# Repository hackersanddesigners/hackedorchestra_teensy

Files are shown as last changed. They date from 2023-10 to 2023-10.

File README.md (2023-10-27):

 

# HACKED ORCHESTRA - TEENSY WORKSHOP

Documentation for Sound Parasites developed for the Hacked Orchestra workshops (H&D, Ghenwa Noiré, Sonic Acts, Muziekgebouw aan het IJ, funded by AFK and Stifo). We've built two types of sound parasites to be used with active components on the line in (e.g. bicycle dynamos, solar panels, piezo transducers, pick up coils) that pick up sounds around us hidden in textures and different materials. One sound parasite adds an echo/delay and the other one adds a granular effect and pitchshifting. Both have a reverb switch implemented as well. 

The sound parasites can be mounted in tin cans (saluting the early DIY electronic instrument builders), but for the purposes of this workshop we will stick to breadboarding because it is easier to troubleshoot in a workshop setting.

This work is inspired by Nic Collins' *Handmade Electronic Music* and Paul Stoffsregen's work on the Teensy + Audio Module as shown in [this workshop](https://www.pjrc.com/store/audio_tutorial_kit.html). 

## Workshop outline 13 oct 23

Check it out here: 

[https://etherpad.hackersanddesigners.nl/p/HackedOrchestra_13Oct](https://etherpad.hackersanddesigners.nl/p/HackedOrchestra_13Oct)

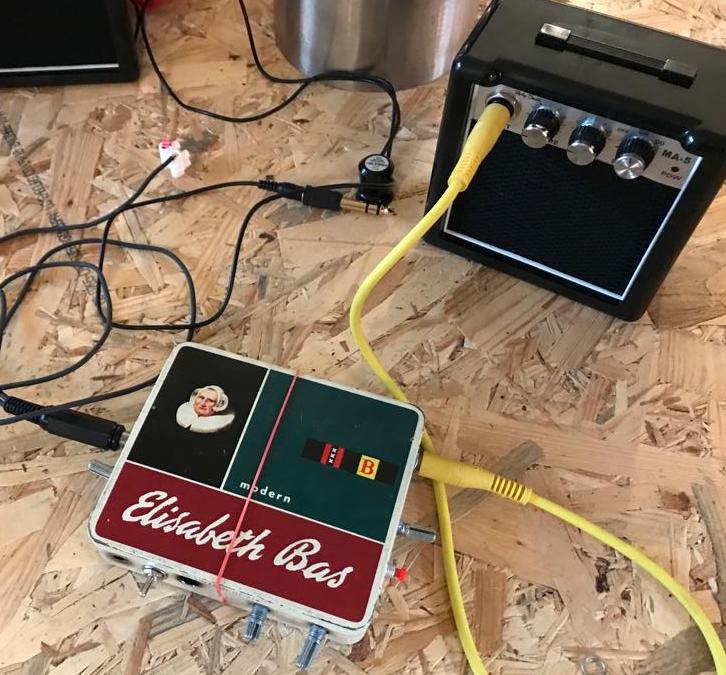
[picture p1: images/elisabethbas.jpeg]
 

### Wishlist based on workshop

* ~~rising/fallingEdge function not great fit w toggle switch, change to simple digitalRead~~
* find out how to protect line in
* ~~more descriptive serial output for the effect sketches (DONE)~~
* ~~controlling line in level w knob doesnt seem to work? (FIXED)~~
* ~~re-do wiring diagram (DONE)~~
* ~~write equalizer code for low pass, high pass, band pass filter (DONE)~~

## BOM 

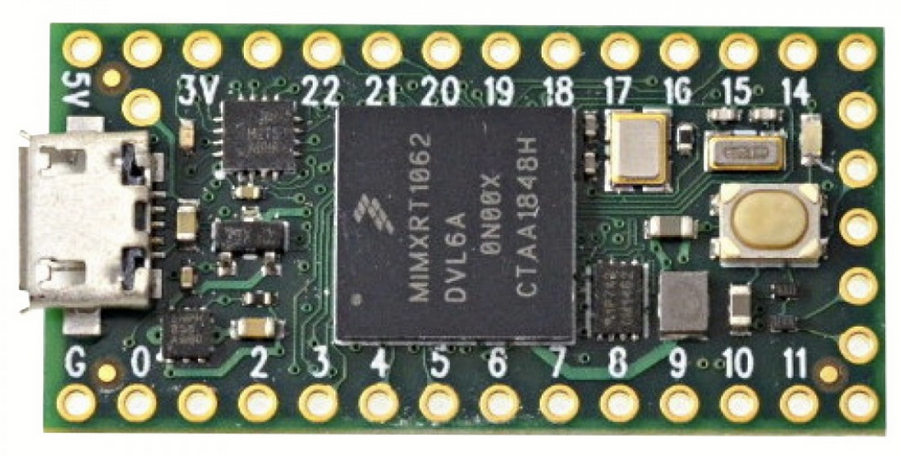
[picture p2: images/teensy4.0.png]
 
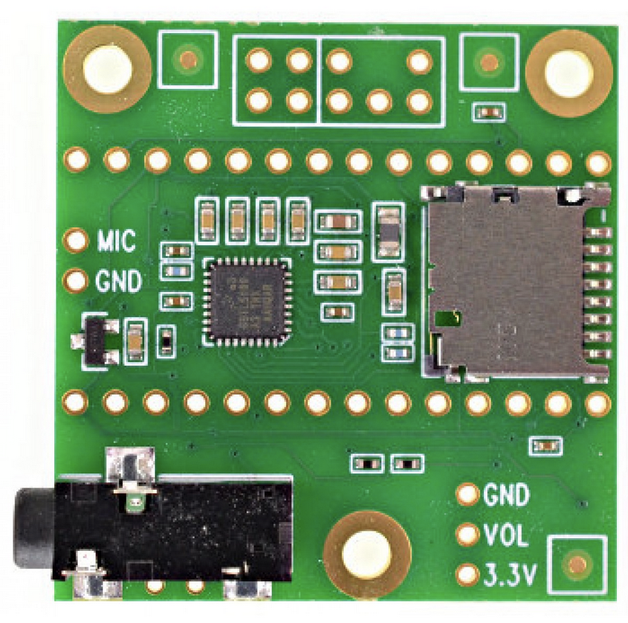
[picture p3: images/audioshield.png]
 

* [Teensy 4.0 - without headers](https://www.tinytronics.nl/shop/en/development-boards/microcontroller-boards/teensy/teensy-4.0) € 27,50 via TinyTronics or Open Circuit
* [Teensy Audio Adapter Board for Teensy 4.0](https://www.tinytronics.nl/shop/en/development-boards/accessories/adapter-boards/teensy-audio-adapter-board-for-teensy-4.0) € 16,25 via TinyTronics or Open Circuit
* [Male pin header, 2x 14 positions](https://www.tinytronics.nl/shop/en/cables-and-connectors/connectors/pin-headers/male/40-pins-header-male) € 0,50 via TinyTronics
* [Breakaway male header 90 degrees](https://www.tinytronics.nl/shop/en/cables-and-connectors/connectors/pin-headers/male/40-pins-header-male-90-degrees) € 0,50 via TinyTronics 
* [Female header 11 mm pin height, scored and broken into 2 rows of 14 positions](https://www.tinytronics.nl/shop/en/cables-and-connectors/connectors/pin-headers/female/40-pins-header-female-11mm-pin-height) € 1 via TinyTronics
* [Micro USB cable](https://www.tinytronics.nl/shop/en/cables-and-connectors/cables-and-adapters/usb/micro-usb/micro-usb-cable-50cm) € 1,24 via TinyTronics
* 4x [10k potentiometer, breadboard compatible](https://www.tinytronics.nl/shop/en/components/resistors/potentiometers/10k%CF%89-potmeter-standard) € 0,41 each via TinyTronics
* Dupont jumper wires, male-male and male-female
* 2x[Jack chassis 6.3 mm](https://www.allekabels.nl/jack-stekker/42/1307777/jack-chassisdeel.html) € 0,99 alle kabels
* [6,3 mm jack patch cables, set](https://www.conrad.nl/nl/p/paccs-jack-kabel-6x-jackplug-male-6-3-mm-6x-jackplug-male-6-3-mm-30-00-cm-meerkleurig-301277.html) € 6.99 Conrad 
* battery-powered mini guitar amp with 6.3 mm jack line in/out [e.g.](https://www.thomannmusic.com/harley_benton_ma_5_miniamp.htm) € 15
* [Piezo transducers](https://www.tinytronics.nl/shop/en/audio/speakers/buzzers/piezo-electronic-buzzer-with-soldered-wires-35mm) € 0,41 Tinytronics
* Bicycle dynamos, second-hand/salvaged
* 2x[Solar cells 5V ](https://www.tinytronics.nl/shop/en/power/solar-energy/solar-panels/solar-panel-5v-200ma-110x80mm) € 2,89
* [Telephone pick-up mic](https://www.amazon.com/Telephone-Microphone-Suction-Cup-Pickup/dp/B0034I75IK) € 8
* [Terminal strip](https://www.tinytronics.nl/shop/en/cables-and-connectors/connectors/screw-terminals/terminal-strip-12-lanes) € 1,24 Tinytronics
* [Shielded audio cable](https://www.conrad.nl/nl/p/bkl-electronic-1509008-audiokabel-1-x-0-22-mm-zwart-per-meter-457893.html) € 1,49 per meter, Conrad
* 4x [Solderable mono jack plugs 6.35 mm € 0,44](https://www.kabelshop.nl/Nedis-6-35-mm-jack-plug-Nedis-Mono-Mannelijk-CAVC23980BK-i15077-t9799.html)

**Plus:for version with breadboard**
* [Large breadboard](https://www.tinytronics.nl/shop/en/tools-and-mounting/prototyping-supplies/breadboards/breadboard-830-points) € 3,31 tinytronics
* A power bank (or plug USB cable into laptop or wall socket adapter)
* [momentary switch 12mm](https://www.tinytronics.nl/shop/en/switches/manual-switches/pcb-switches/tactile-pushbutton-switch-momentary-4pin-12*12*7.3mm) € 0,12 via tinytronics
* [cap for momentary switch 12 mm](https://www.tinytronics.nl/shop/en/components/knobs,-caps-and-covers/button-cap-for-tactile-pushbutton-switch-momentary-12x12x7.3mm-yellow) €0,12 via Tinytronics
* [toggle switch](https://www.tinytronics.nl/shop/en/switches/manual-switches/slide-switches/small-switch-for-pcb-or-breadboard) € 0,17 via tinytronics

**Plus: for version inside a case** 
* 1x [Momentary switch](https://www.tinytronics.nl/shop/en/switches/manual-switches/push-buttons-and-switches/black-button-7mm) € 0,41 each via TinyTronics
* 1x [toggle switch](https://www.tinytronics.nl/shop/en/switches/manual-switches/toggle-switches/standard-built-in-flip-switch-mts-102) € 0,60 via TinyTronics
* [LilyGO TTGO 18650 battery charging board](https://www.tinytronics.nl/shop/en/power/bms-and-chargers/li-ion-and-li-po/with-protection-circuit/lilygo-ttgo-t-bat-with-18650-battery-holder-cn3065) € 4,55 via tinytronics
* [18650 li-ion battery 3500mAh/10A](https://www.tinytronics.nl/shop/en/power/batteries/18650/lg-18650-li-ion-battery-3400mah-10a-inr18650-mj1) € 4,96 via Tinytronics
* [JST-PH compatibel connector, 2 pos](https://www.tinytronics.nl/shop/en/cables-and-connectors/cables-and-adapters/jst-compatible/jst-2.0mm-connector-with-cable-ph2.0-2-pins) € 0,33 via Tinytronics
* [perfboard 2.54 mm spacing with lanes/strips](https://www.tinytronics.nl/shop/en/tools-and-mounting/prototyping-supplies/experiment-pcbs/experiment-pcb-6.5cm*14.5cm-lanes) €1,65 via TinyTronics

# Sounds Around: Material Symmetries

There are lots of signals around us that can be be sonified and/or amplified. What goes up, must come down, what gives will receive. A speaker is a mic is a speaker, a motor is a generator is a motor. Silent signals, textures, movements, vibrations: all can be explored with these simple probes. Wire one up and find out: 

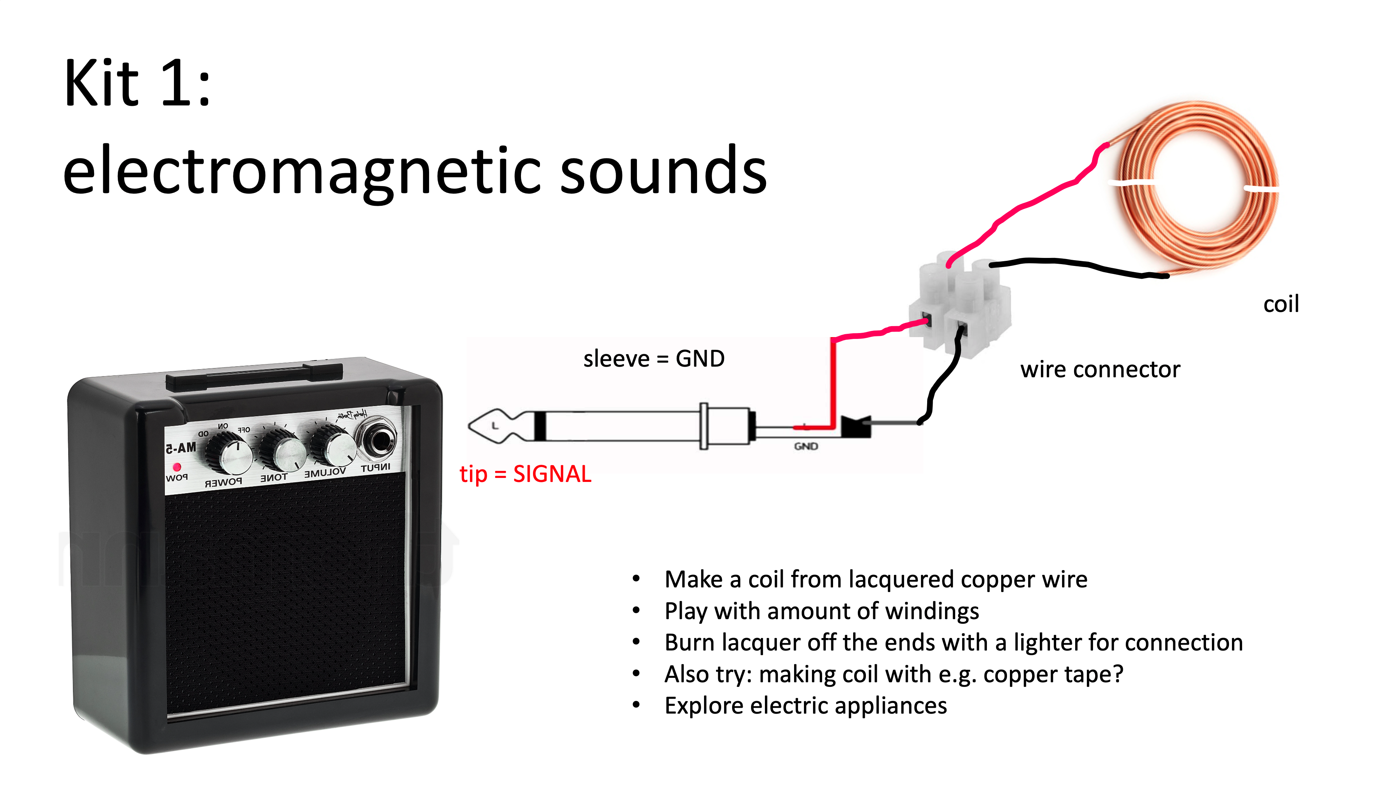
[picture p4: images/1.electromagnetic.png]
 

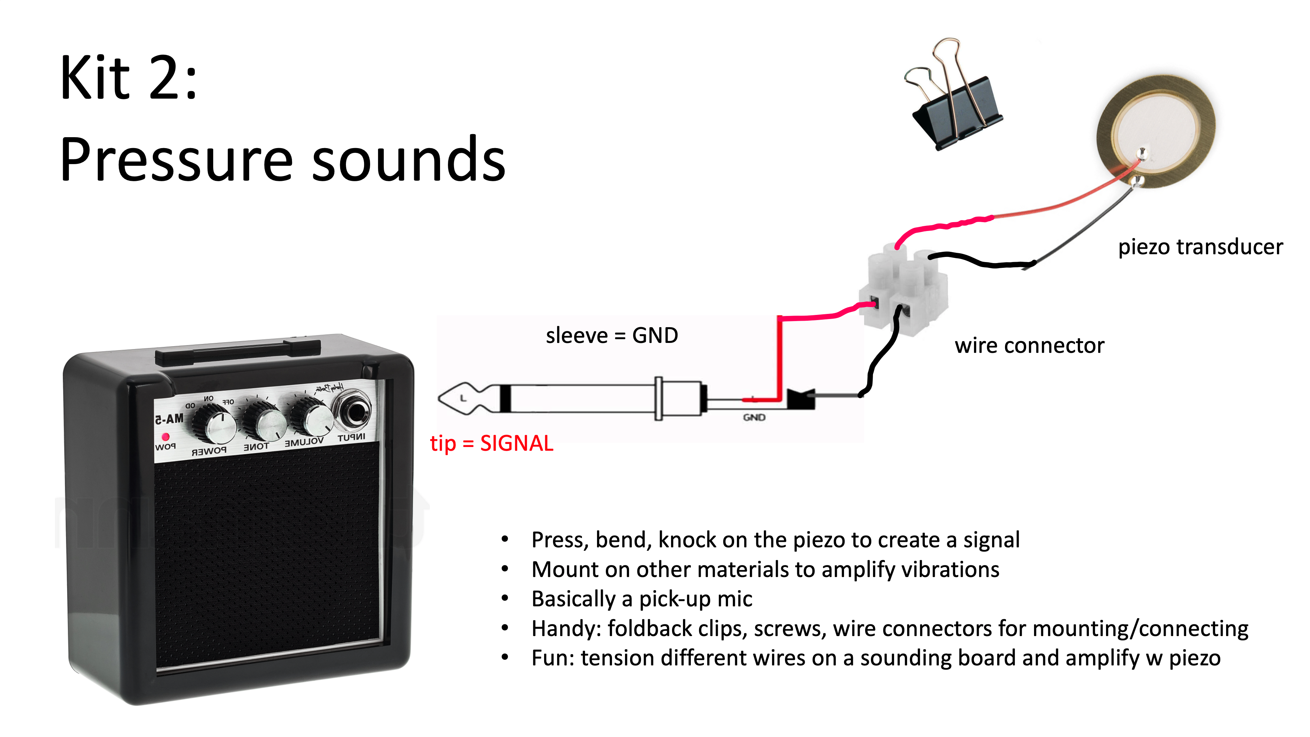
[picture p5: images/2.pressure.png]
 

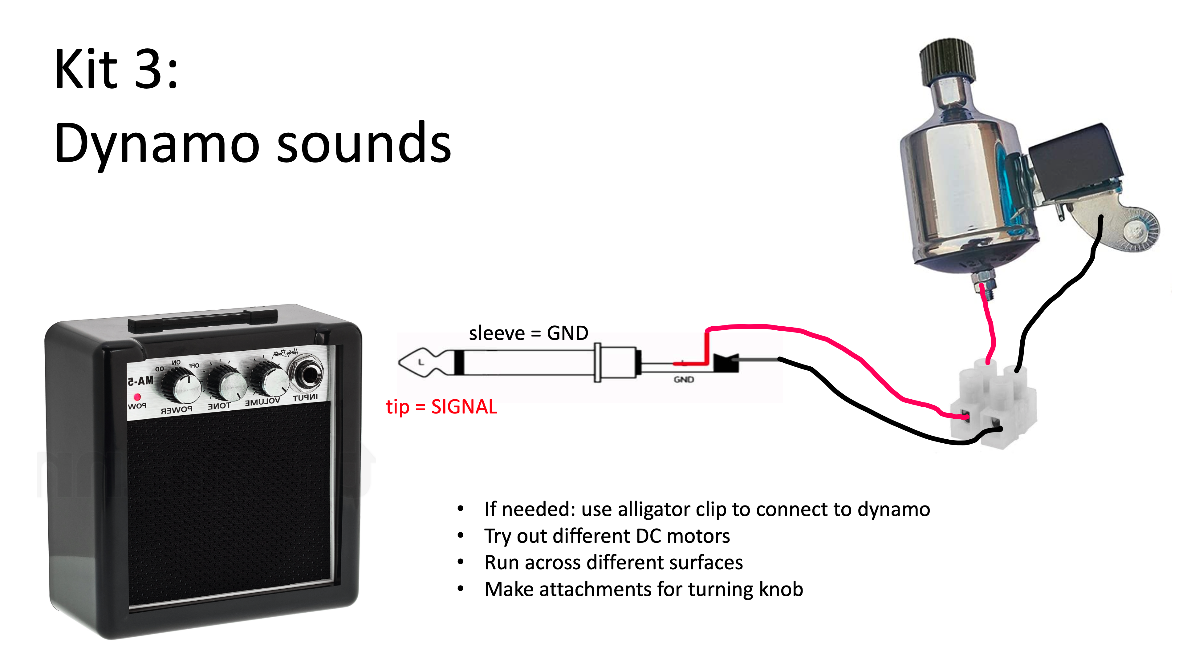
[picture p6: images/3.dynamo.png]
 

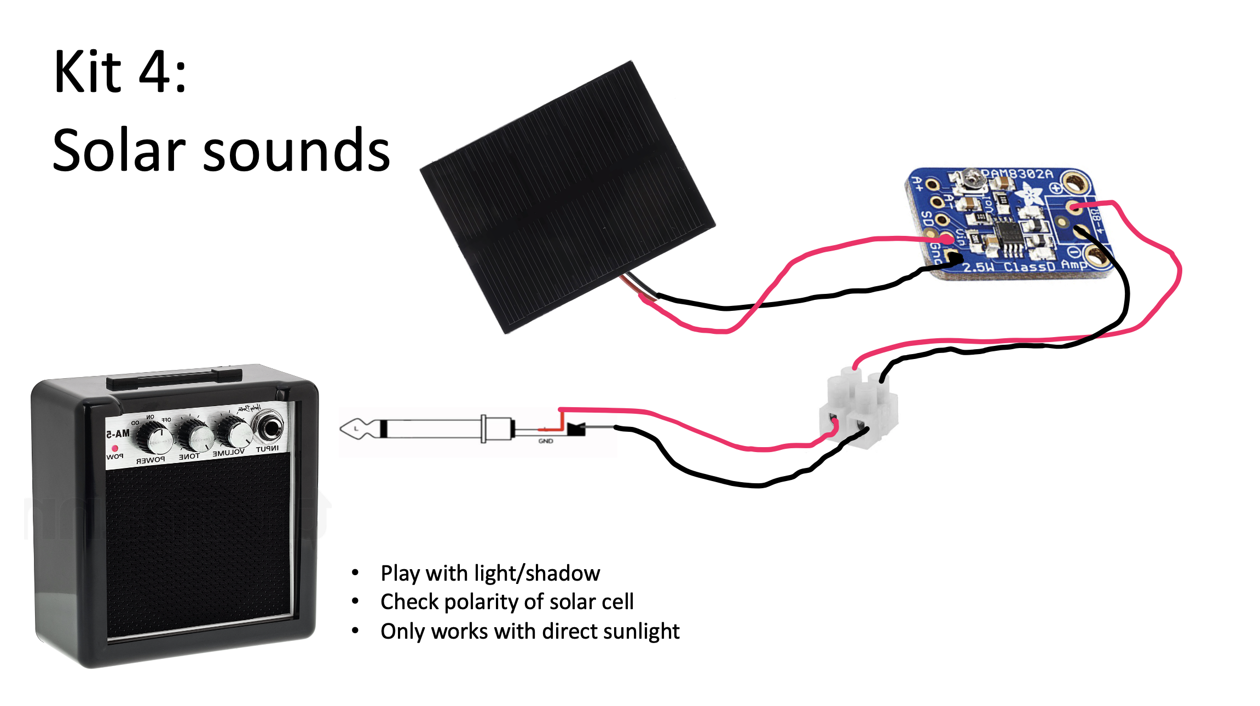
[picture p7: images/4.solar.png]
 

# Building Sound Parasites

## Assembling the circuit

* Score the straight male and female header strips with a stanley knife or dremel and break them into rows of 14. 
* break two pieces from the 90 degree angled header: one with 2 positions and one with 3 positions. 

### Assembling with a breadboard

The teensy board will be pressed into the breadboard, the male pins of the female header should stick out of the bottom of the board. The audio shield will go on top of it, so needs the male header pins sticking out downwards also. So we want to: 

* Solder the female header strips with the long legs through the teensy board 
* solder the male header strips to the bottom of the audio shield
* solder the small angled headers to the line in and line out on the audio shield 

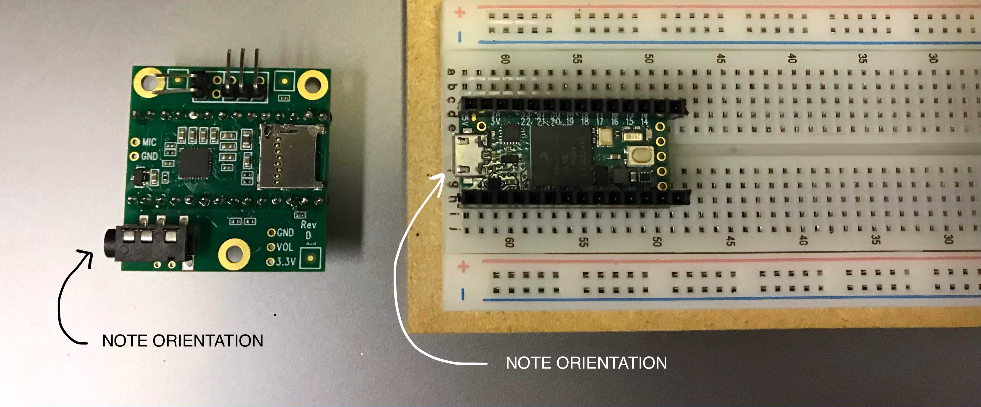
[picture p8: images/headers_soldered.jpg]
 

* Gently press the header on top of the teensy board. Be careful not to bend the legs.

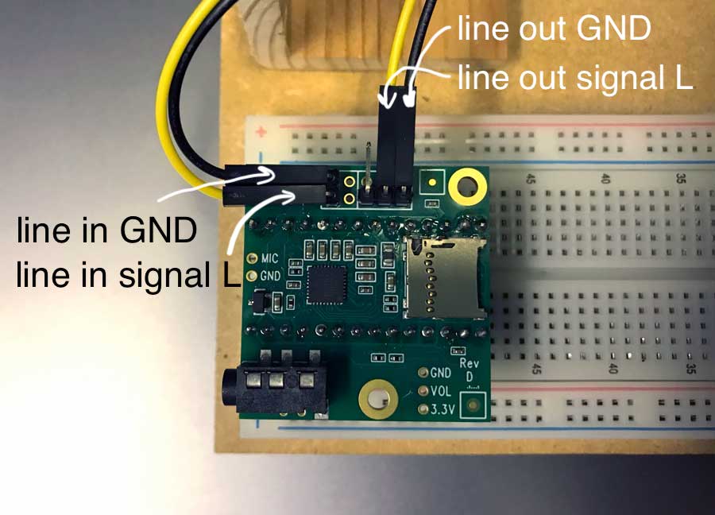
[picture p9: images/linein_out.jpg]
 

* You can connect the left jack receptacle to the LINE IN pins (black to GND, yellow to SIGNAL L)
* And connect the right jack receptacle to the LINE OUT pins (black to GND, yellow to SIGNAL L)

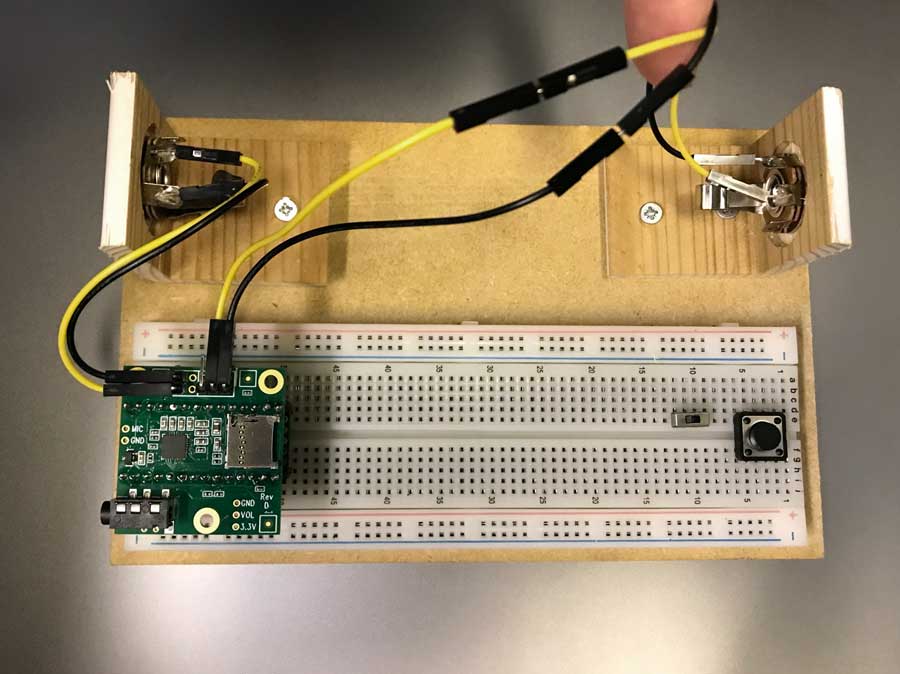
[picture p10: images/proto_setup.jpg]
 

* With this in place you can connect a probe (e.g. a piezo) as input on the line in (left), and a jack cable going to the speaker on the line out (right). 

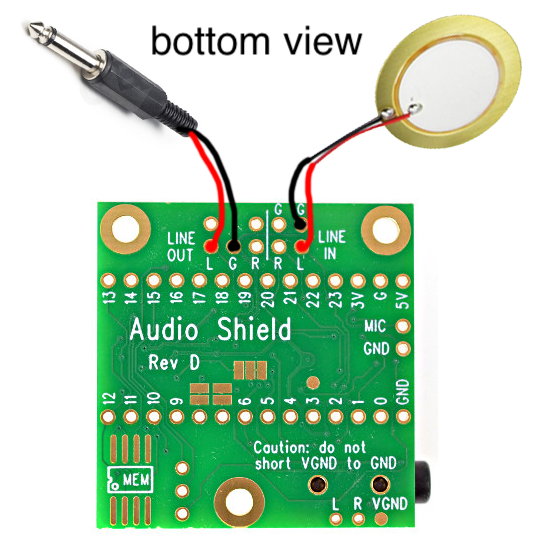
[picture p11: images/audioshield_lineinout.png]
 

**Breadboarding**

You will need to connect 4 potentiometers (turning knobs), a toggle switch, and a momentary switch to the breadboard. You can follow this wiring diagram. You might have a switch that looks slightly different. Just make sure to connect one leg to ground, and the other to the pin 0 (for a slide or toggle switch) or pin 1 for the momentary switch (pushbutton).

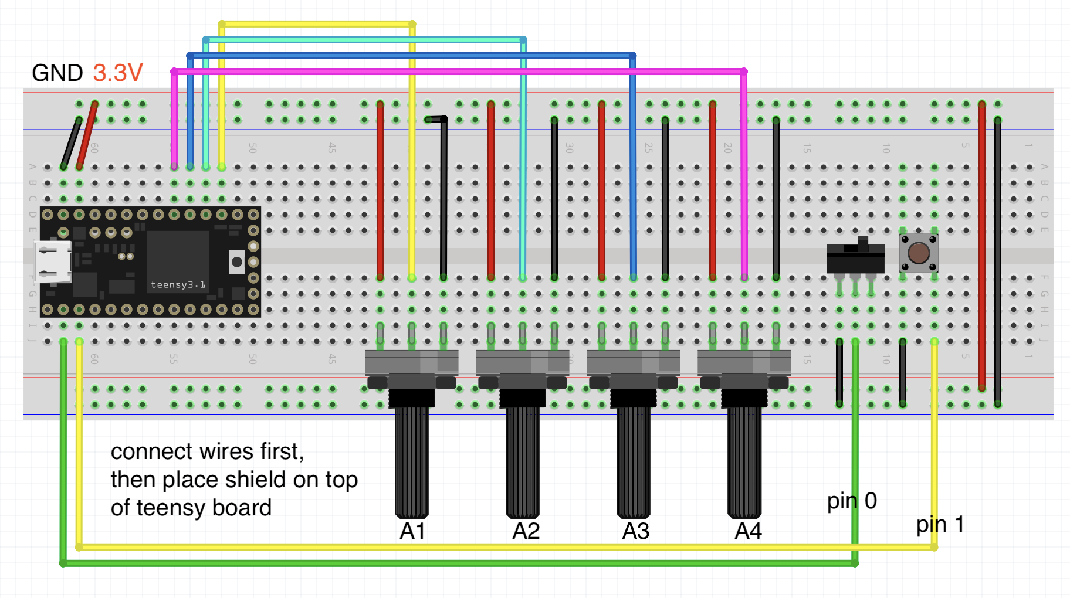
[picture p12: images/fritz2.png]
 

### Assembling inside a box

This requires a slightly different approach because stacking the headers like we did for the breadboard makes the stack really high. So we will bend the stacking headers outwards to keep it more flat.

* bend the female headers with the long leg into a 90 degree angle: stick one into the holes of the board but not all the way (leave 1 mm to allow for bending) and bend them to 90 degree angle.  
* solder them to the teensy board
* solder the straight male header strips to the audio shield
* solder the small angled headers to the line in and line out on the audio shield

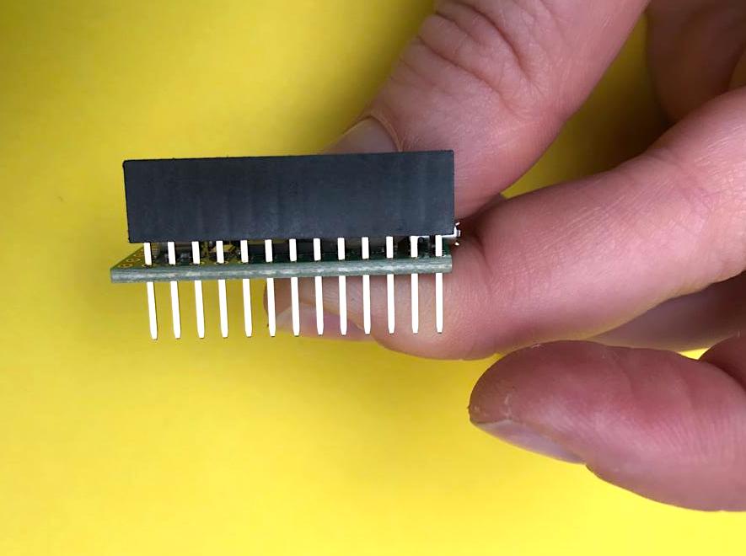
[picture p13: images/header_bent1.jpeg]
 
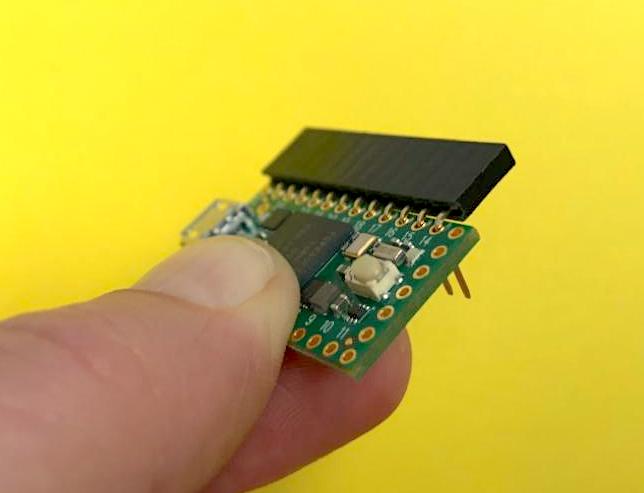
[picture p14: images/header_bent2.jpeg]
 
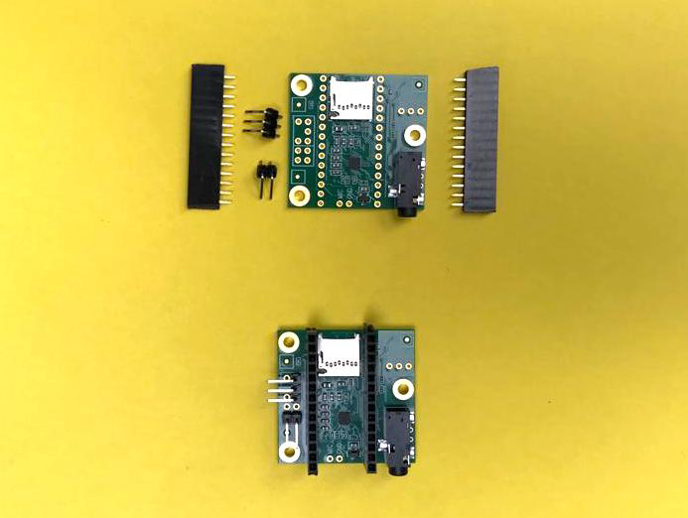
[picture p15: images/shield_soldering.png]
 
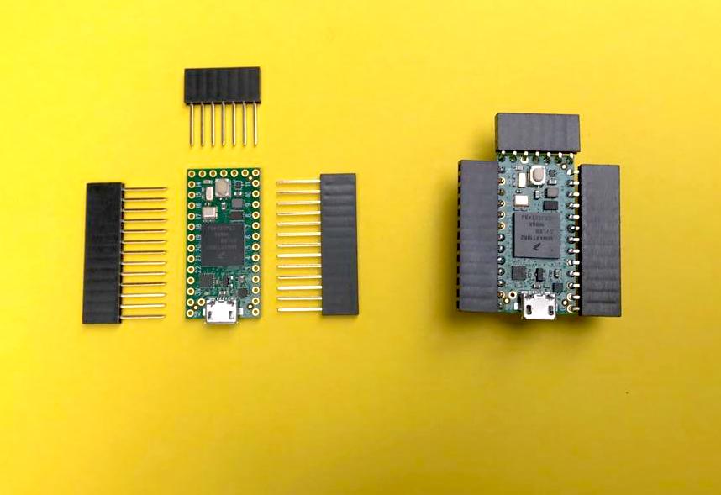
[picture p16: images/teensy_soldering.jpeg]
 

## Install for Mac & Arduino 2.2.x.

Add link below to the JSON board manager URL in the preference panel of Arduino IDE: 

```
https://www.pjrc.com/teensy/package_teensy_index.json
```

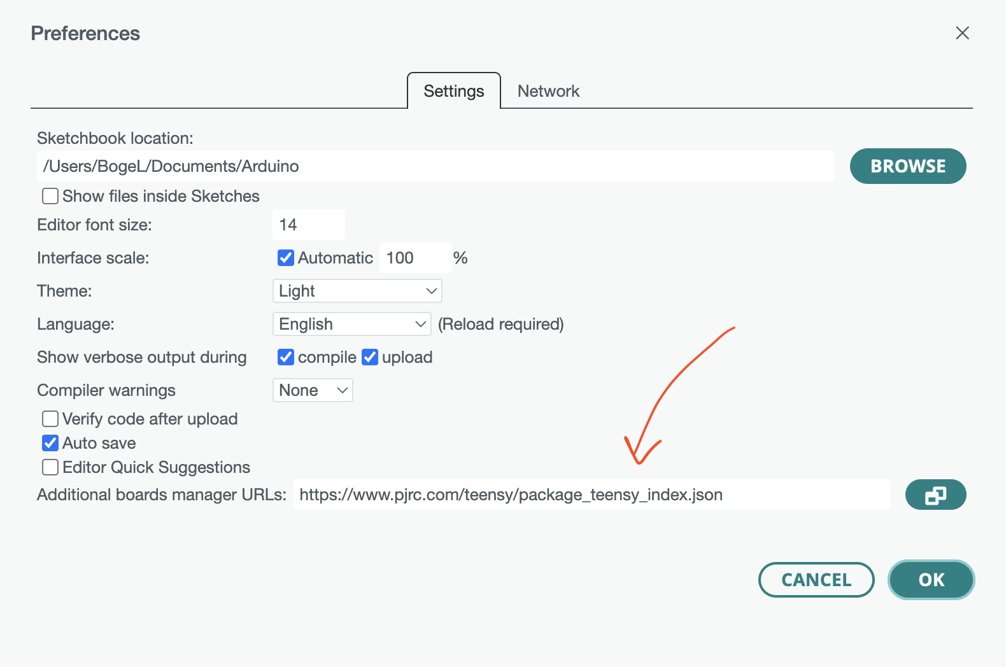
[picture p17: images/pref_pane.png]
 

Then install via > Tools > Boards > Boards Manager (search for "Teensy")

Installing separate Teensy Loader is not necessary, it comes with board install. 

More info on other OS: [https://www.pjrc.com/teensy/td_download.html](https://www.pjrc.com/teensy/td_download.html)

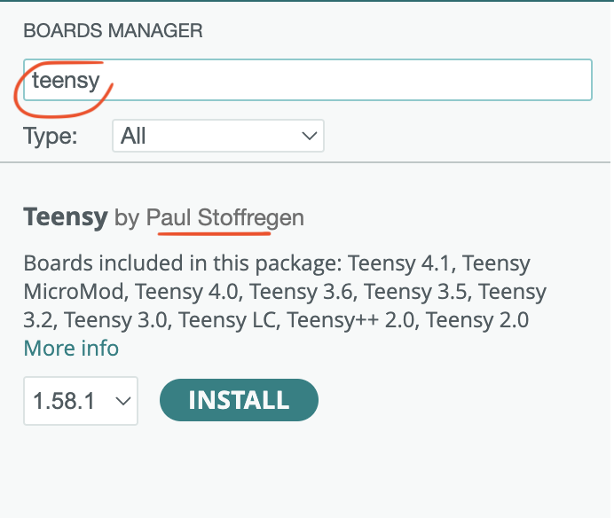
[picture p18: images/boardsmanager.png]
 

### Choosing board & port

**Board**

Choose Teensy 4.0 from board menu under > Tools > Board

**Port**

When plugged in, a section called "Teensy Ports" shows up under > Tools > Port. On mac the port looks something like */dev/cu.usbmodemxxxxxxx Serial (Teensy 4.0)*

There might sometimes be some hassle with ports, then hit boot button on the teensy board and try again. Check the monitor for errors and hints on how to trouble shoot.

## Hardware test

First we want to check if all the hardware is wired correctly and working. Open the "hardware_test" from the code folder in this repository and upload it to the board (you can find it in the menu under > Sketch > Upload). 

1. Is the teensy chip programmed and live?
> if an LED on the board is blinking it means the board is powered and working!

2. Is the line out to the speaker functioning? 
> If you hear a beep every other second, your line out works!

3. Is the line in (probe to board) functioning? 
> if you touch the piezo disk connected to the line in, you should hear its sounds amplified through the speaker. 

3. Is the Teensy able to communicate with your computer? 
>  Open the serial monitor (in the menu under > Tools > Serial Monitor)
> Select teensy in the "Serial" section under > Tools > Port)
> Note: you need to switch between ports everytime when switching between uploading and using the serial monitor
> If you see numbers appearing continuously, the Teensy can communicate with the computer!

4. Are the knobs and switches wired correctly?
> Turn one of the knobs: if the numbers change (between 0-1023) as you turn, this knob is working correctly!
> Try the same for the other knobs
> Try the switches, if you press them or slide/toggle them the serial monitor should alternate between 0s and 1s (for voltage LOW or HIGH)

ALL SYSTEMS GO! Let's look at the code.

## Audio system design tool 

The hardware test defines a the audio elements above the setup. This is generated with a special Teensy Design system with a node based GUI. Copy paste these elements from the code and import them into the design tool with the IMPORT button. It will show you which elements are in the design and allows you to look up parameters of the different functions. This is useful if you want to change the code later: it tells you what is possible with these libraries.

[https://www.pjrc.com/teensy/gui/index.html](https://www.pjrc.com/teensy/gui/index.html)

Open in **SAFARI**! In Firefox you can drag and drop but not delete things.

You can import the code from Arduino to look at the nodes and connections: 

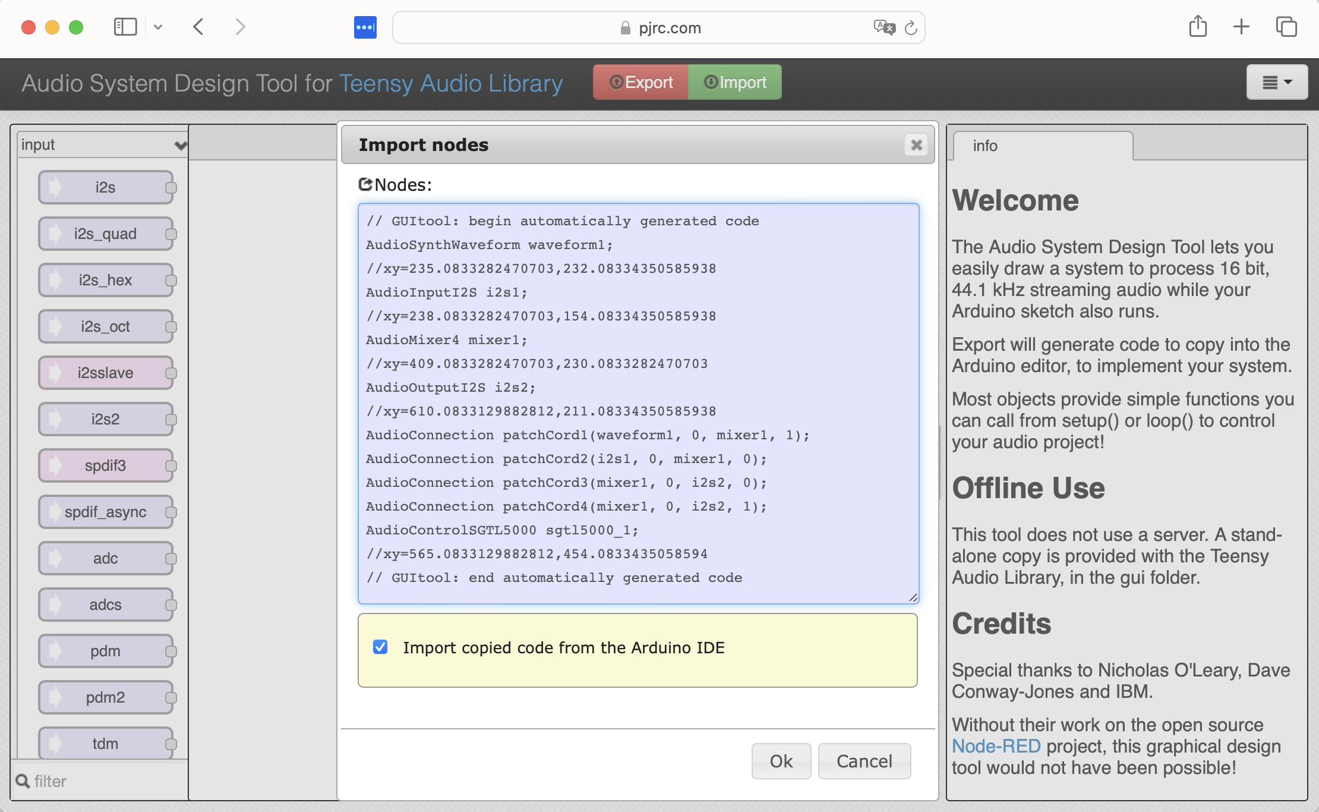
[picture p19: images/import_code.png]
 
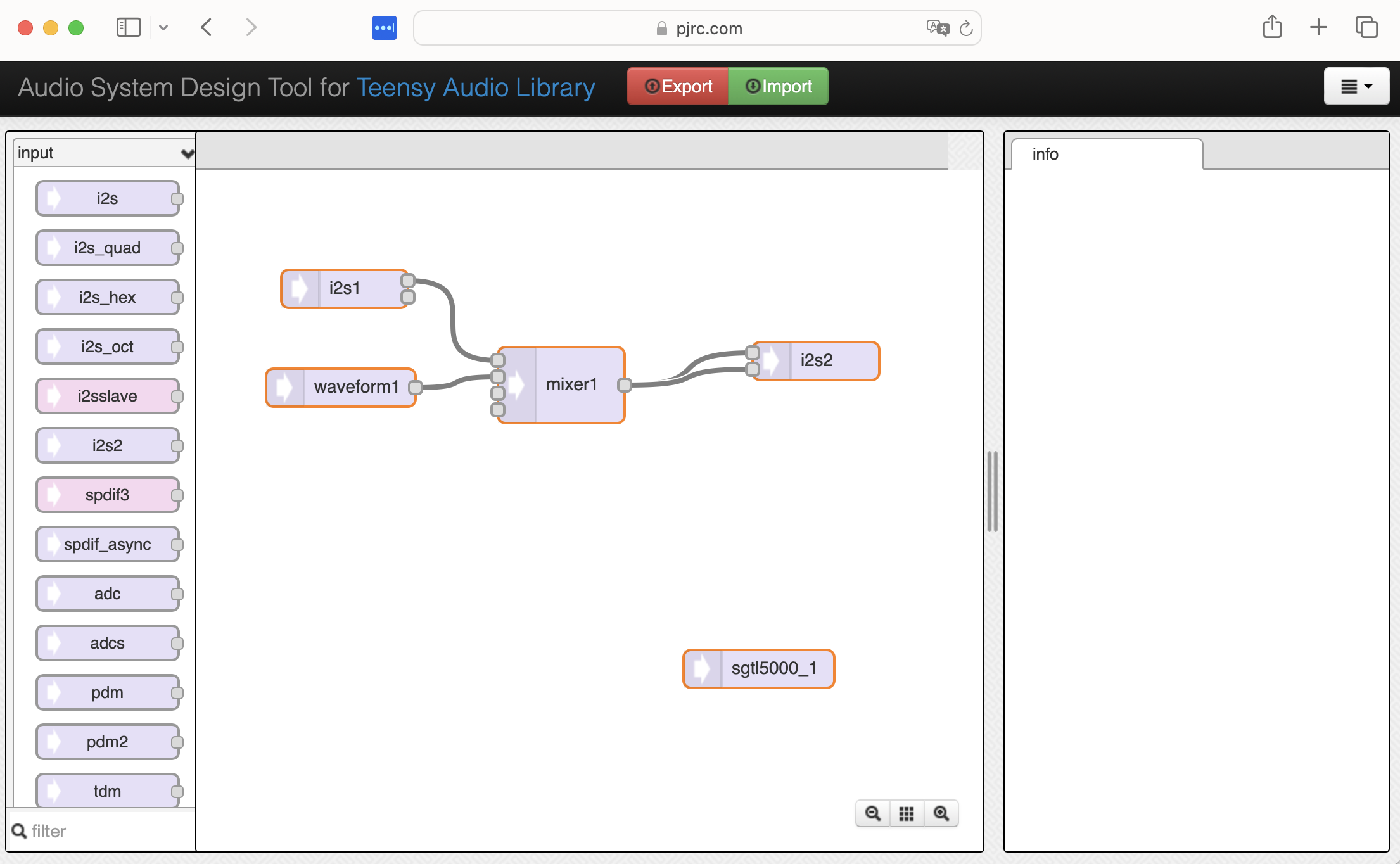
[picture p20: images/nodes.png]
 

Or you can create your own nodes and connections and export it with the EXPORT button. Then you copy these settings into your Arduino sketch (should be above the setup() function).

## Our sound parasites

Now we verified that everything works we can upload the code for the sound parasites. There's two types: one with echo (delay) and one with a granular effect/pitchshifting. Both have a reverb switch programmed in as well. 

### Pitch shift

If you look in the code, you can see that we commented what everything does. Here's an overview as well: 

- Pot 1 - A1 -> Input gain
- Pot 2 - A2 -> Granular pitchShift grainLength
- Pot 3 - A3 -> Granular speed ratio
- Pot 4 - A4 -> Reverb time
- Btn 1 - D0 -> Toggle - effects on/off
- Btn 2 - D1 -> Momentary switch - reverb on/off

### Echo

- Pot 1 - A1 -> gain line in
- Pot 2 - A2 -> delay time
- Pot 3 - A3 -> decay
- Pot 4 - A4 -> Reverb time
- Btn 1 - D0 -> Toggle - effects on/off
- Btn 2 - D1 -> Momentary switch - reverb on/off

## Teensy pinout

Below is the pinout of the Teensy 4.0. You can see there's a built-in LED on pin13, and pins 14-23 can also be used as analog pins (A0-A9). The pins marked with PWM can be used for analog writing to outputs (e.g. fading LEDs or spinning motors faster and slower).

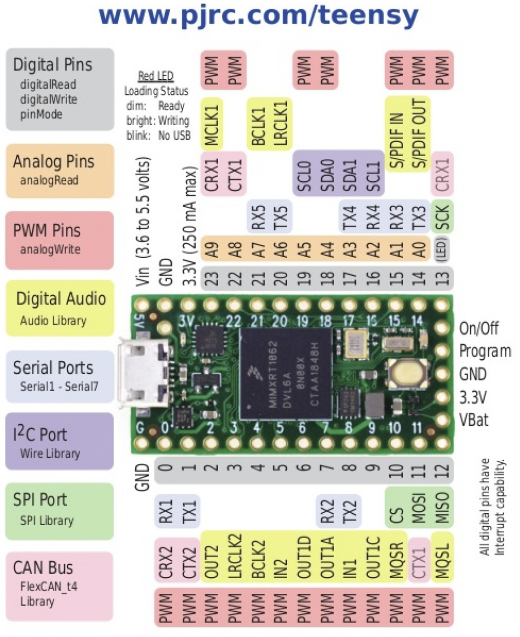
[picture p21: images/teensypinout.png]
 

## Note on recording and playback (not used here)

With the record example you can make a recording either with the mix or with the line in on the board. It generates a .raw file that you can import into Audacity and convert into something else. It overwrites the file every time you record and recording time is 9-s	10 secs or so

## Workshop outline 13 oct 23

Check it out here: 

[https://etherpad.hackersanddesigners.nl/p/HackedOrchestra_13Oct](https://etherpad.hackersanddesigners.nl/p/HackedOrchestra_13Oct)

## Kids workshop outline

[https://etherpad.hackersanddesigners.nl/p/HackedOrchestra_7Oct](https://etherpad.hackersanddesigners.nl/p/HackedOrchestra_7Oct)

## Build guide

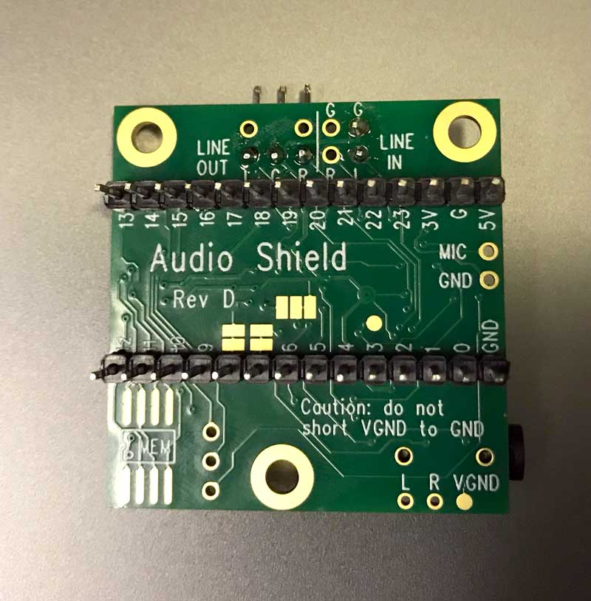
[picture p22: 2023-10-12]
images/soldered_shield_bottom.jpg

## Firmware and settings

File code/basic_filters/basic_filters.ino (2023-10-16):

// check out this vid for explanation of EQ filters
// pass filters = filtering out certain frequencies
// frequency (90-10000), stage (cascading up to 4: 1-3), and Q shape
// lowshelf & highshelf = boosting frequencies in a lower resp higher range.
// stage (0-3), freq (90-10K), gain (< 5), slope (smooth or sudden transition)
// https://www.youtube.com/watch?v=-_ghMYWIz0g
// should look into biquad a bit but gets technical quick

#include <Bounce.h>
#include <Audio.h>
#include <Wire.h>
#include <SPI.h>
#include <SD.h>
#include <SerialFlash.h>

//connect LEDs on pin 3, 4 and 5 to indicate which filter is active
#define led1 3
#define led2 4
#define led3 5

Bounce button1 = Bounce(1, 15);  // debounce time 15 ms
int counter = 0;
int prevCounter = 0;

int lineInLevel;
float freqLow;
float freqHigh;
float freqBand;

const int myInput = AUDIO_INPUT_LINEIN;  // alternatively: AUDIO_INPUT_MIC;

String filter = "no filter";

// GUItool: begin automatically generated code
AudioInputI2S i2s1;         //xy=257,241
AudioFilterBiquad biquad1;  //xy=415,241
AudioMixer4 mixer1;         //xy=568,223
AudioOutputI2S i2s2;        //xy=735,252
AudioConnection patchCord1(i2s1, 0, biquad1, 0);
AudioConnection patchCord2(i2s1, 0, mixer1, 0);
AudioConnection patchCord3(biquad1, 0, mixer1, 1);
AudioConnection patchCord4(mixer1, 0, i2s2, 0);
AudioConnection patchCord5(mixer1, 0, i2s2, 1);
AudioControlSGTL5000 sgtl5000_1;  //xy=463,313
// GUItool: end automatically generated code

void setup() {

  Serial.begin(9600);
  delay(3000);
  Serial.println("Started.");
  Serial.println("no filter");

  pinMode(1, INPUT_PULLUP);  //switch
  pinMode(led1, OUTPUT);     // led
  pinMode(led2, OUTPUT);     // led
  pinMode(led3, OUTPUT);     // led
  digitalWrite(led1, LOW);
  digitalWrite(led2, LOW);
  digitalWrite(led3, LOW);

  AudioMemory(200);

  sgtl5000_1.enable();  // Enable the audio shield
  sgtl5000_1.inputSelect(myInput);
  sgtl5000_1.lineInLevel(0);  //gain of line in on start (0-15)
  sgtl5000_1.volume(0.5);

  mixer1.gain(0, 0.8);  // direct from line in, default
  mixer1.gain(1, 0);    //filter in, default off

  delay(2000);
}


void loop() {
  // update pushbutton
  button1.update();

  // read knobs
  float knobA1 = (float)analogRead(A1);  // sets lineInLevel
  float knobA2 = (float)analogRead(A2);  // set frequency of low/high/bandpass filter

  // control the gain on line in w knob
  lineInLevel = map(knobA1, 0, 1023, 0, 15);  // Line In gain 0-15 max
  sgtl5000_1.lineInLevel(lineInLevel);

  if (button1.fallingEdge()) {
    prevCounter = counter;
    counter++;
  }

  if (counter == 0) {
    // feedthrough line in, filter off, leds off
    analogWrite(led1, 0);
    analogWrite(led2, 0);
    analogWrite(led3, 0);
    mixer1.gain(0, 0.8);  //feedthrough gain
    mixer1.gain(1, 0);    //filter gain
    String filter = "no filter";
    if (counter != prevCounter) {
      Serial.println(filter);
    }
    prevCounter = 0;
    Serial.print("Gain line in A1 ");
    Serial.print(lineInLevel);
    Serial.print("  |  filters off ");
    Serial.println();
  }

  if (counter == 1) {
    analogWrite(led1, 512);                                //turn on led (PWM 50% in case no resistors)
    analogWrite(led2, 0);
    analogWrite(led3, 0);
    mixer1.gain(0, 0);                                    //feedthrough gain
    mixer1.gain(1, 0.8);                                  //filter gain
    freqLow = expf((float)knobA2 / 150.0) * 10.0 + 80.0;  // quick and dirty equation for exp scale frequency adjust
    biquad1.setLowpass(0, freqLow, 0.5);                  // setLowpass(stage 0-3, corner frequency 90-10k, Q shape < 0.70)
    String filter = "lowpass";
    if (counter != prevCounter) {
      Serial.println(filter);
    }
    prevCounter = 1;
    Serial.print("Gain line in A1 ");
    Serial.print(lineInLevel);
    Serial.print("  |  lowpass freq A2 ");
    Serial.println(freqLow);
  }

  if (counter == 2) {
    analogWrite(led1, 0);
    analogWrite(led2, 512);                                //turn on led (PWM 50% in case no resistors)
    analogWrite(led3, 0);
    mixer1.gain(0, 0);                                     //feedthrough gain
    mixer1.gain(1, 0.8);                                   //filter gain
    freqHigh = expf((float)knobA2 / 150.0) * 10.0 + 80.0;  // quick and dirty equation for exp scale frequency adjust
    biquad1.setHighpass(0, freqHigh, 0.5);                 // setHighpass(stage 0-3, corner frequency 90-10k, Q shape < 0.70)
    String filter = "highpass";
    if (counter != prevCounter) {
      Serial.println(filter);
    }
    prevCounter = 2;
    Serial.print("Gain line in A1 ");
    Serial.print(lineInLevel);
    Serial.print("  |  highpass freq A2 ");
    Serial.println(freqHigh);
  }

  if (counter == 3) {
    analogWrite(led1, 0);
    analogWrite(led2, 0);
    analogWrite(led3, 512);                                //turn on led (PWM 50% in case no resistors)
    mixer1.gain(0, 0);                                     //feedthrough gain
    mixer1.gain(1, 0.8);                                   //filter gain
    freqBand = expf((float)knobA2 / 150.0) * 10.0 + 80.0;  // quick and dirty equation for exp scale frequency adjust
    biquad1.setBandpass(0, freqBand, 0.5);                 // setBandpass(stage 0-3, corner frequency 90-10k, bandwidth 10-5000
    String filter = "bandpass";
    if (counter != prevCounter) {
      Serial.println(filter);
    }
    prevCounter = 3;
    Serial.print("Gain line in A1 ");
    Serial.print(lineInLevel);
    Serial.print("  |  bandpass freq A2 ");
    Serial.println(freqBand);
  }

  if (counter > 3) {
    counter = 0;
  }
}

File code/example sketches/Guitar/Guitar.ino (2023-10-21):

#include <Audio.h>
#include <Wire.h>
#include <SD.h>
#include <SPI.h>
#include <SerialFlash.h>

#include "chords.h"

// Special thanks to Matthew Rahtz - http://amid.fish/karplus-strong/

AudioSynthKarplusStrong  string1;
AudioSynthKarplusStrong  string2;
AudioSynthKarplusStrong  string3;
AudioSynthKarplusStrong  string4;
AudioSynthKarplusStrong  string5;
AudioSynthKarplusStrong  string6;
AudioMixer4              mixer1;
AudioMixer4              mixer2;
AudioOutputI2S           i2s1;
AudioConnection          patchCord1(string1, 0, mixer1, 0);
AudioConnection          patchCord2(string2, 0, mixer1, 1);
AudioConnection          patchCord3(string3, 0, mixer1, 2);
AudioConnection          patchCord4(string4, 0, mixer1, 3);
AudioConnection          patchCord5(mixer1, 0, mixer2, 0);
AudioConnection          patchCord6(string5, 0, mixer2, 1);
AudioConnection          patchCord7(string6, 0, mixer2, 2);
AudioConnection          patchCord8(mixer2, 0, i2s1, 0);
AudioConnection          patchCord9(mixer2, 0, i2s1, 1);
AudioControlSGTL5000     sgtl5000_1;

const int finger_delay = 5;
const int hand_delay = 220;

int chordnum=0;

void setup() {
  AudioMemory(15);
  sgtl5000_1.enable();
  sgtl5000_1.volume(0.6);
  mixer1.gain(0, 0.15);
  mixer1.gain(1, 0.15);
  mixer1.gain(2, 0.15);
  mixer1.gain(3, 0.15);
  mixer2.gain(1, 0.15);
  mixer2.gain(2, 0.15);
  delay(700);
}

void strum_up(const float *chord, float velocity);
void strum_dn(const float *chord, float velocity);

void loop() {
  const float *chord;

  // each time through the loop, play a different chord
  if (chordnum == 0) {
    chord = Cmajor;         // change to any chord specified in the .h file
    Serial.println("C major");
    chordnum = 1;
  } else if (chordnum == 1) {
    chord = Gmajor;         // change to any chord specified in the .h file
    Serial.println("G major");
    chordnum = 2;
  } else if (chordnum == 2) {
    chord = Aminor;       // change to any chord specified in the .h file
    Serial.println("A minor");
    chordnum = 3;
  } else {
    chord = Eminor;       // change to any chord specified in the .h file
    Serial.println("E minor");
    chordnum = 0;
  }

  // then strum the 6 string several times
  strum_up(chord, 1.0);
  delay(hand_delay);
  delay(hand_delay);
  strum_up(chord, 1.0);
  delay(hand_delay);
  strum_dn(chord, 0.8);
  delay(hand_delay);
  delay(hand_delay);
  strum_dn(chord, 0.8);
  delay(hand_delay);
  strum_up(chord, 1.0);
  delay(hand_delay);
  strum_dn(chord, 0.8);
  delay(hand_delay);
  strum_up(chord, 1.0);
  delay(hand_delay);
  delay(hand_delay);
  strum_up(chord, 1.0);
  delay(hand_delay);
  strum_dn(chord, 0.7);
  delay(hand_delay);
  delay(hand_delay);
  strum_dn(chord, 0.7);
  delay(hand_delay);
  strum_up(chord, 1.0);
  delay(hand_delay);
  strum_dn(chord, 0.7);
  delay(hand_delay);

  Serial.print("Max CPU Usage = ");
  Serial.print(AudioProcessorUsageMax(), 1);
  Serial.println("%");
}

void strum_up(const float *chord, float velocity)
{
  if (chord[0] > 20.0) string1.noteOn(chord[0], velocity);
  delay(finger_delay);
  if (chord[1] > 20.0) string2.noteOn(chord[1], velocity);
  delay(finger_delay);
  if (chord[2] > 20.0) string3.noteOn(chord[2], velocity);
  delay(finger_delay);
  if (chord[3] > 20.0) string4.noteOn(chord[3], velocity);
  delay(finger_delay);
  if (chord[4] > 20.0) string5.noteOn(chord[4], velocity);
  delay(finger_delay);
  if (chord[5] > 20.0) string6.noteOn(chord[5], velocity);
  delay(finger_delay);
}

void strum_dn(const float *chord, float velocity)
{
  if (chord[5] > 20.0) string1.noteOn(chord[5], velocity);
  delay(finger_delay);
  if (chord[4] > 20.0) string2.noteOn(chord[4], velocity);
  delay(finger_delay);
  if (chord[3] > 20.0) string3.noteOn(chord[3], velocity);
  delay(finger_delay);
  if (chord[2] > 20.0) string4.noteOn(chord[2], velocity);
  delay(finger_delay);
  if (chord[1] > 20.0) string5.noteOn(chord[1], velocity);
  delay(finger_delay);
  if (chord[0] > 20.0) string6.noteOn(chord[0], velocity);
  delay(finger_delay);
}

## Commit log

2023-09-27 update bom
2023-09-28 add reverb button & mixer
2023-10-05 add buttons. Untested but i think (hope?) it works
2023-10-07 add blinking led
2023-10-08 update_readme
    update readme, add pics
    [breadboard_fritz.fzz]
2023-10-08 add wiring audioshield
    [breadboard_fritz.fzz]
2023-10-08 add parts
    [breadboard_fritz.fzz]
2023-10-12 pinmode for led
2023-10-12 add probes
2023-10-15 add lo-hi-band-pass and wiring diagram
    [breadboard_fritz copy.fzz]
2023-10-27 add zine
    [jack_holder_volkan_dincer.stl]
